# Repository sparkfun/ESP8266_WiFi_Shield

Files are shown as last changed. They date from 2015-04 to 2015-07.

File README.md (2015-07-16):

SparkFun ESP8266 WiFi Shield
========================================

SparkFun ESP8266 WiFi Shield

[*SparkFun ESP8266 WiFi Shield (WRL-13287)*](https://www.sparkfun.com/products/13287)

The [SparkFun ESP8266 WiFi Shield](https://www.sparkfun.com/products/13287) is essentially an Arduino shield for the ESP8266 WiFi SoC. The ESP8266 ships with a slightly customized version of the Espressif AT command set.

The ESP8266 is controlled by serial AT commands. The shield is equipped with a switch to swap between a software serial port or hardware serial port interface.

Repository Contents
-------------------

* **/Firmware** - Firmware flashed on the ESP8266 WiFi Shield (requires ESP8266 SDK 1.2.0)
* **/Hardware** - Eagle design files (.brd, .sch)
* **/Production** - Production panel files (.brd)

Documentation
--------------
* **[Hookup Guide](https://learn.sparkfun.com/tutorials/esp8266-wifi-shield-hookup-guide)** - Exhaustive hookup guide for the ESP8266 WiFi Shield.

Product Versions
----------------
* [DEV-13287](https://www.sparkfun.com/products/13287)- V1.0 release of the WiFi Shield.

License Information
-------------------
This product is _**open source**_! 

The **hardware** is released under [Creative Commons ShareAlike 4.0 International](https://creativecommons.org/licenses/by-sa/4.0/).

The **code** is beerware; if you see me (or any other SparkFun employee) at the local, and you've found our code helpful, please buy us a round!

Please use, reuse, and modify these files as you see fit. Please maintain attribution to SparkFun Electronics and release anyWiFi Shield derivative under the same license.

Distributed as-is; no warranty is given.

- Your friends at SparkFun.

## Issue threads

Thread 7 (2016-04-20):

Shield not working?

r3m4k3, 2016-04-20:
Hi there,

I have wired Arduino Mega 2560 with your shield.
I have uploaded demo code and it returns me false in line eso8266.begin(), what does it mean?
Does it mean, that the hardware is corrupt?
Then, how can I get information, what is precisely broken?
Can I check for example voltage or something for pins and then know or hardware is down, or maybe I had bad soldered the goldpins, or there is a short circuit.

Thanks, best regards

bboyho, 2019-02-11:
Hi,

I was checking something in the GitHub repository and noticed this issue filed.

###Software Serial Pins

The ESP8266 Shield was designed to stack on the Arduino Uno footprint with the ATmega328P microcontroller. Not all pins on the Arduino Mega 2560 support change interrupts for Rx so software serial will not work on pin 8. Check out this note from Arduino.cc on the Software Serial Library =>  [https://www.arduino.cc/en/Reference/softwareSerial](https://www.arduino.cc/en/Reference/softwareSerial) ]. You can probably get it working on the Arduino Mega 2560 by [redefining the library on pin 8](https://github.com/sparkfun/SparkFun_ESP8266_AT_Arduino_Library/blob/master/src/SparkFunESP8266WiFi.h#L34) to:

    #define ESP8266_SW_TX	10

You will also need to reroute the pin so that the ESP8266's Tx pin connects pin 10.

###Solder Joints

Just like any basic troubleshooting, you should also [check your solder joints](https://learn.sparkfun.com/tutorials/sparkfun-troubleshooting-tips#bad-solder-joints). However, I do not believe this is the issue.

Closed 2019-02-11.

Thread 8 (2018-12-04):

Arduino reset (and additional firmware features)

jaketesler, 2018-12-04:
Hello!
@jimblom SparkFun told me opening an issue here was the best avenue to ask my question to you directly.

I have a question regarding the most-recent published build of the ESP8266 shield firmware.
https://github.com/sparkfun/ESP8266_WiFi_Shield/blob/749e0c4b562e96147a4b3361443263421a739eb5/Firmware/include/user_config.h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 https://github.com/sparkfun/ESP8266_WiFi_Shield/blob/749e0c4b562e96147a4b3361443263421a739eb5/Firmware/user/at_ArduinoShield.c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

These two sections of the code seem to indicate that it's possible to reset an Arduino using no hardware modifications (except modifying SJ4), and furthermore the schematic (https://cdn.sparkfun.com/assets/learn_tutorials/4/0/3/SparkFun-ESP8266-WiFi-Shield.pdf) seems to indicate that, with the proper firmware build, this should be possible.

The current published build on this repo doesn't seem to include source code for these features, and the `AT+DUINORST` command doesn't currently work on my own shield.

My question is, is there another (newer) version of the firmware and a way I could acquire a build of it (or the source), or, if a newer version doesn't exist, would it be possible to upload the remainder of the codebase (for compilation) so I can work on coding and developing the features into the SF source code here?

Thanks Jim!
-Jake Tesler

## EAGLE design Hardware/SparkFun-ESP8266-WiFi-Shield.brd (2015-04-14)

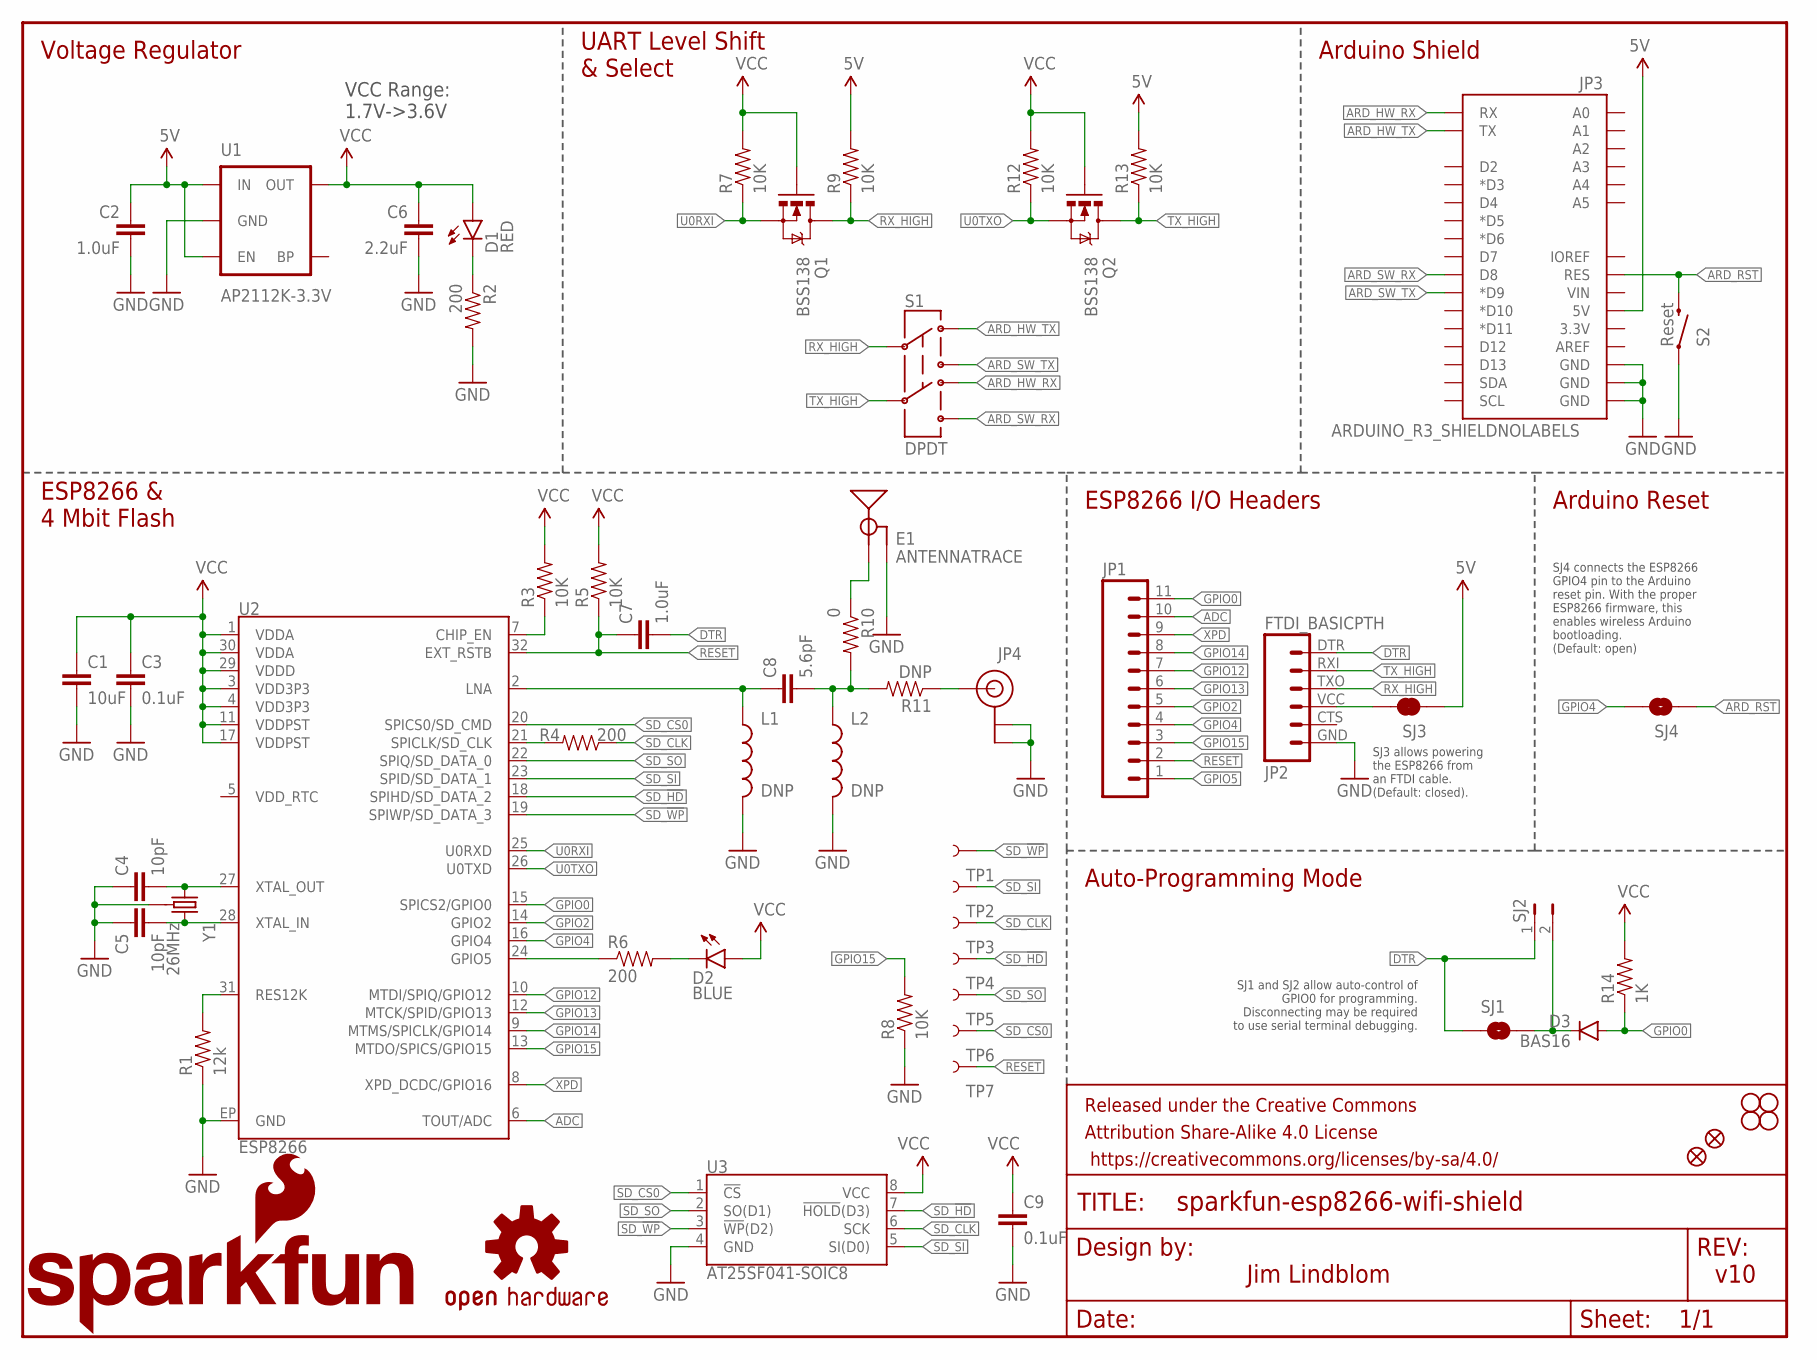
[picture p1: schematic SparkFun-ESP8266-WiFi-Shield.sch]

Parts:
C1: 10uF; 0603-CAP
C2: 1.0uF; 0805
C3, C9: 0.1uF; 0603-CAP
C4, C5: 10pF; 0603-CAP
C6: 2.2uF; 0603-CAP
C7: 1.0uF; 0603-CAP
C8: 5.6pF; 0603-CAP
D1: RED; LED-0603
D2: BLUE; LED-0603
D3: BAS16; SOD-323
E1: ANTENNATRACE; TRACE_ANTENNA_2.4GHZ_25.7MM
FID1, FID2: FIDUCIAL1X2; FIDUCIAL-1X2
FRAME1: FRAME-LETTER; CREATIVE_COMMONS
JP1: M11PTH; 1X11
JP2: FTDI_BASICPTH; FTDI_BASIC
JP3: ARDUINO_R3_SHIELDNOLABELS; UNO_R3_SHIELD_NOLABELS
JP4: U.FL
L1, L2: DNP; 0603
LOGO1: SFE_LOGO_NAME_FLAME.2_INCH; SFE_LOGO_NAME_FLAME_.2
LOGO2: OSHW-LOGOM; OSHW-LOGO-M
Q1, Q2: BSS138; SOT23-3
R1: 12k; 0603-RES
R2, R4, R6: 200; 0603-RES
R3, R5, R7, R8, R9, R12, R13: 10K; 0603-RES
R10: 0; 0603
R11: DNP; 0603-RES
R14: 1K; 0603-RES
S1: DPDT; AYZ0202
S2: Reset; TACTILE-SWITCH-SMD
SJ1: JUMPER-PAD-2-NO; PAD-JUMPER-2-NO_NO_SILK
SJ2: JUMPER-PTH-2-NO; PTH-JUMPER-2-NO_NO_SILK
SJ3: JUMPER-PAD-2-NC_BY_TRACE; PAD-JUMPER-2-NC_BY_TRACE_YES_SILK
SJ4: JUMPER-PAD-2-NOYES_SILK; PAD-JUMPER-2-NO_YES_SILK
STANDOFF1, STANDOFF2, STANDOFF3, STANDOFF4: STAND-OFF
TP1, TP2, TP3, TP4, TP5, TP6, TP7: TEST-POINT3X5; PAD.03X.05
U1: AP2112K-3.3V; SOT23-5
U2: ESP8266; QFN32
U3: AT25SF041-SOIC8; SO08
Y1: 26MHz; CRYSTAL-SMD-3.2X2.5

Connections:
5V: C2.1, JP3.5V, R9.2, R13.2, SJ3.1, U1.1 (IN), U1.3 (EN)
ADC: JP1.10, U2.6 (TOUT/ADC)
ANT: JP4.P$3 (SIGNAL), R11.1
ARD_HW_RX: JP3.RX, S1.4
ARD_HW_TX: JP3.TX, S1.1
ARD_RST: JP3.RES, S2.3 (2), SJ4.1
ARD_SW_RX: JP3.D8, S1.6
ARD_SW_TX: JP3.D9 (*D9), S1.3
CHIP_EN: R3.1, U2.7 (CHIP_EN)
DTR: C7.2, JP2.DTR (1), SJ1.1, SJ2.1
GND: C1.2, C2.2, C3.2, C4.1, C5.1, C6.2, C9.2, E1.GND, E1.GND2 (GND), JP2.GND (6), JP3.GND@0 (GND), JP3.GND@1 (GND), JP3.GND@2 (GND), JP4.P$1 (GND), JP4.P$2 (GND), L1.2, L2.2, R1.1, R2.2, R8.1, S2.1, U1.2 (GND), U2.EP (GND), U3.4 (GND), Y1.2 (GND), Y1.4 (GND)
GPIO0: D3.A, JP1.11, R14.1, U2.15 (SPICS2/GPIO0)
GPIO2: JP1.5, U2.14 (GPIO2)
GPIO4: JP1.4, SJ4.2, U2.16 (GPIO4)
GPIO5: JP1.1, R6.1, U2.24 (GPIO5)
GPIO12: JP1.7, U2.10 (MTDI/SPIQ/GPIO12)
GPIO13: JP1.6, U2.12 (MTCK/SPID/GPIO13)
GPIO14: JP1.8, U2.9 (MTMS/SPICLK/GPIO14)
GPIO15: JP1.3, R8.2, U2.13 (MTDO/SPICS/GPIO15)
LNA: C8.1, L1.1, U2.2 (LNA)
unnamed: R1.2, U2.31 (RES12K)
unnamed: C5.2, U2.28 (XTAL_IN), Y1.3 (2)
unnamed: C4.2, U2.27 (XTAL_OUT), Y1.1
unnamed: D1.C, R2.1
unnamed: C8.2, L2.1, R10.2, R11.2
unnamed: R4.2, U2.21 (SPICLK/SD_CLK)
unnamed: JP2.VCC (4), SJ3.2
unnamed: D2.C, R6.2
RESET: C7.1, JP1.2, R5.1, TP7.P$1, U2.32 (EXT_RSTB)
RX_HIGH: JP2.TXO (3), Q1.3 (D), R9.1, S1.2
SD_!HD!: TP4.P$1, U2.18 (SPIHD/SD_DATA_2), U3.7 (!HOLD!(D3))
SD_!WP!: TP1.P$1, U2.19 (SPIWP/SD_DATA_3), U3.3 (!WP!(D2))
SD_CLK: R4.1, TP3.P$1, U3.6 (SCK)
SD_CS0: TP6.P$1, U2.20 (SPICS0/SD_CMD), U3.1 (!CS!)
SD_SI: TP2.P$1, U2.23 (SPID/SD_DATA_1), U3.5 (SI(D0))
SD_SO: TP5.P$1, U2.22 (SPIQ/SD_DATA_0), U3.2 (SO(D1))
SJ2: D3.C, SJ1.2, SJ2.2
TRACE_ANT: E1.ANT (SIGNAL), R10.1
TX_HIGH: JP2.RXI (2), Q2.3 (D), R13.1, S1.5
U0RXI: Q1.2 (S), R7.1, U2.25 (U0RXD)
U0TXO: Q2.2 (S), R12.1, U2.26 (U0TXD)
VCC: C1.1, C3.1, C6.1, C9.1, D1.A, D2.A, Q1.1 (G), Q2.1 (G), R3.2, R5.2, R7.2, R12.2, R14.2, U1.5 (OUT), U2.1 (VDDA), U2.3 (VDD3P3), U2.4 (VDD3P3), U2.11 (VDDPST), U2.17 (VDDPST), U2.29 (VDDD), U2.30 (VDDA), U3.8 (VCC)
XPD: JP1.9, U2.8 (XPD_DCDC/GPIO16)

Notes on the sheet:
VCC Range: 1.7V->3.6V
SJ1 and SJ2 allow auto-control of GPIO0 for programming. Disconnecting may be required to use serial terminal debugging.
Auto-Programming Mode
ESP8266 I/O Headers
Arduino Shield
UART Level Shift & Select
Voltage Regulator
ESP8266 & 4 Mbit Flash
v10
Jim Lindblom
Arduino Reset
SJ4 connects the ESP8266 GPIO4 pin to the Arduino reset pin. With the proper ESP8266 firmware, this enables wireless Arduino bootloading. (Default: open)
SJ3 allows powering the ESP8266 from an FTDI cable. (Default: closed).

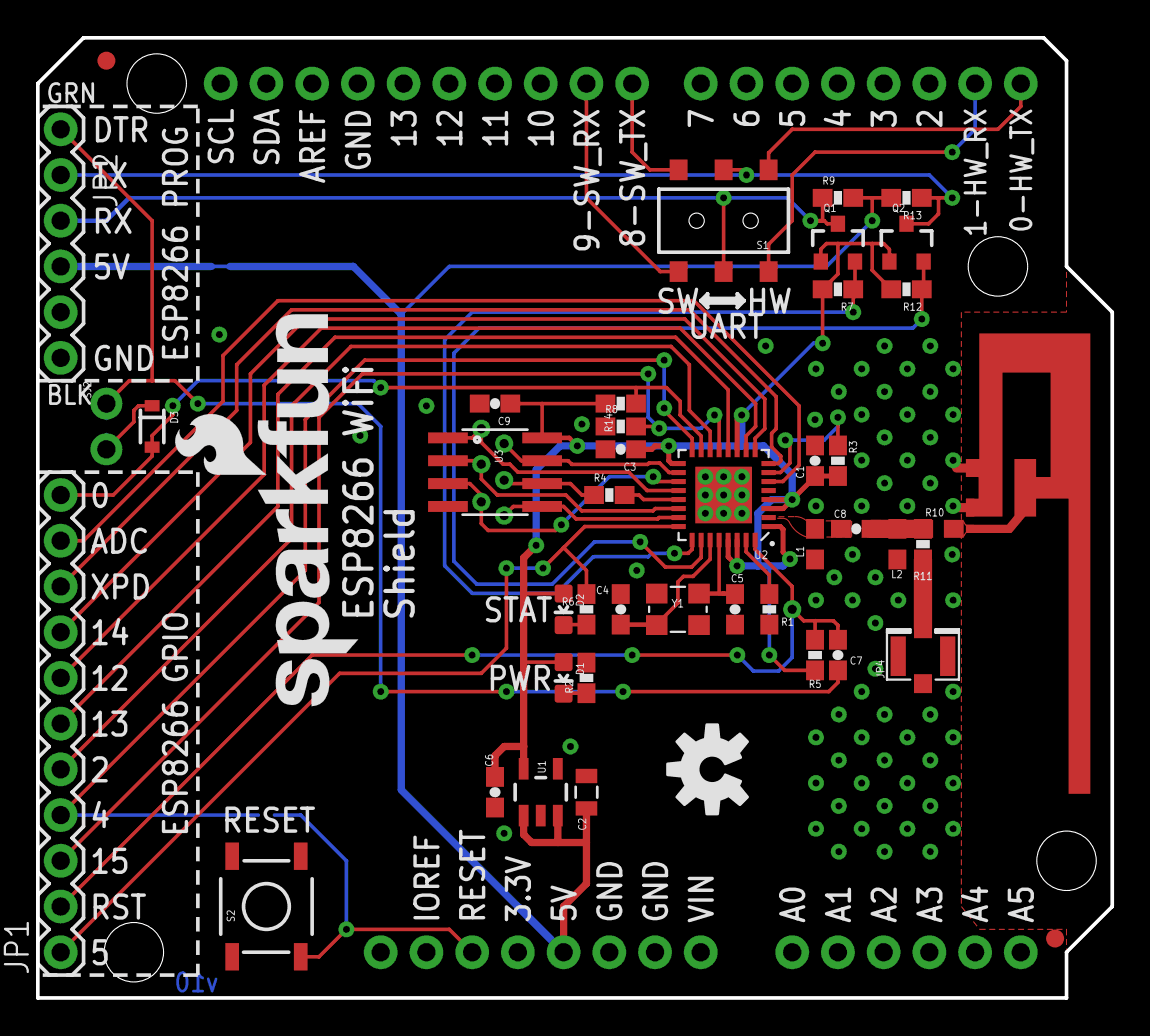
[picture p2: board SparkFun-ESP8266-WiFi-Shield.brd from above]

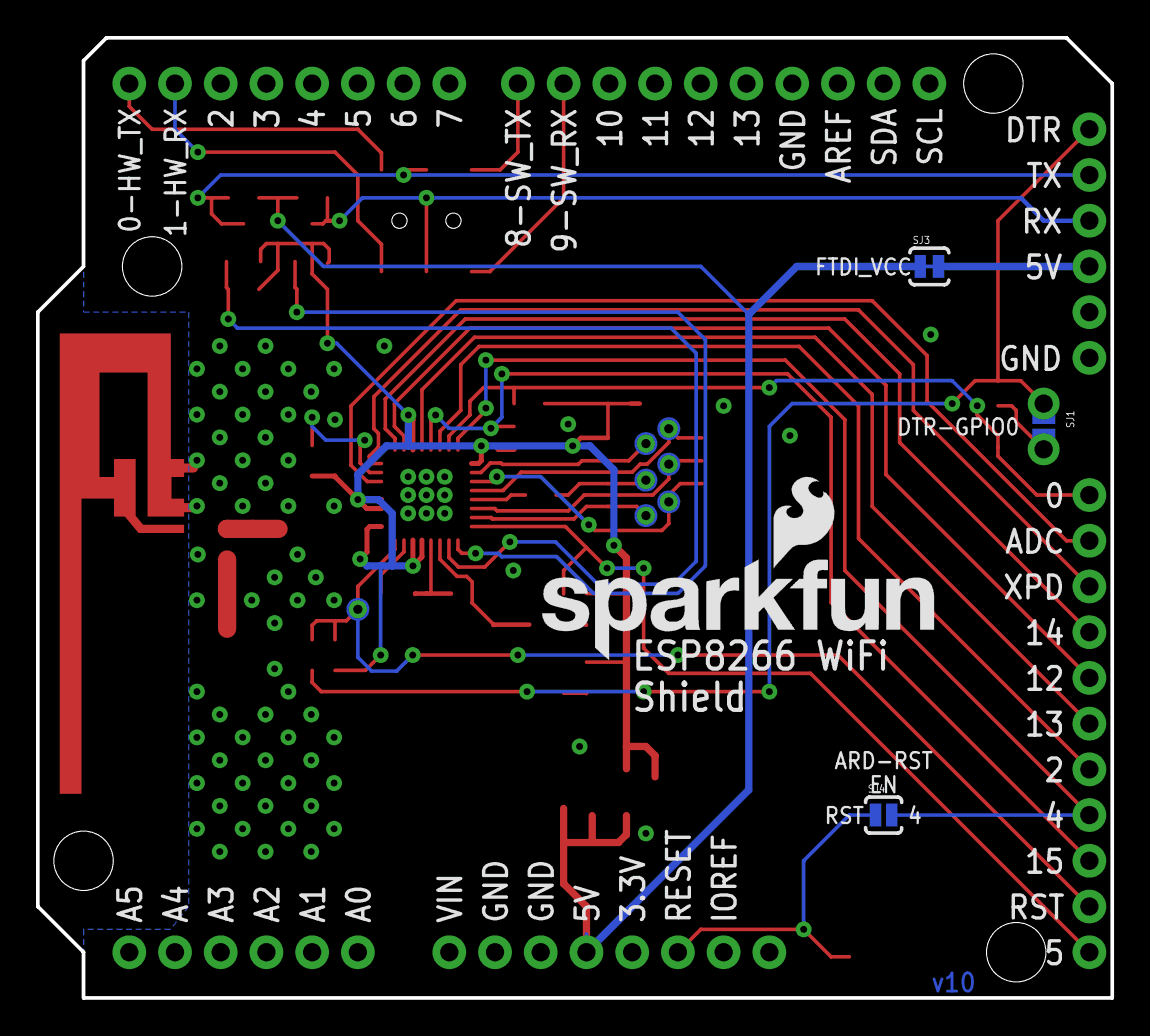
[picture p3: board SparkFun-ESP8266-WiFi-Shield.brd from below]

Board: 2 copper layers, 59.7 x 53.3 mm, 62 parts (11 on the bottom side), 43 nets.

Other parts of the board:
LOGO3: SFE_LOGO_NAME_FLAME.2_INCH; SFE_LOGO_NAME_FLAME_.2

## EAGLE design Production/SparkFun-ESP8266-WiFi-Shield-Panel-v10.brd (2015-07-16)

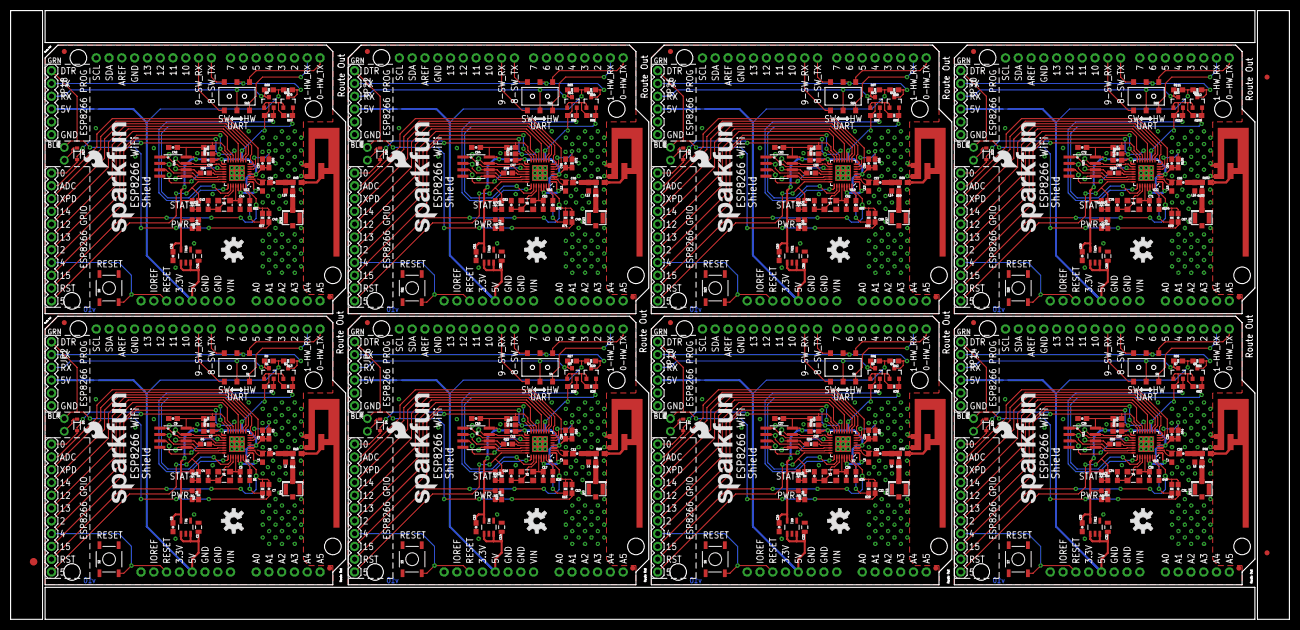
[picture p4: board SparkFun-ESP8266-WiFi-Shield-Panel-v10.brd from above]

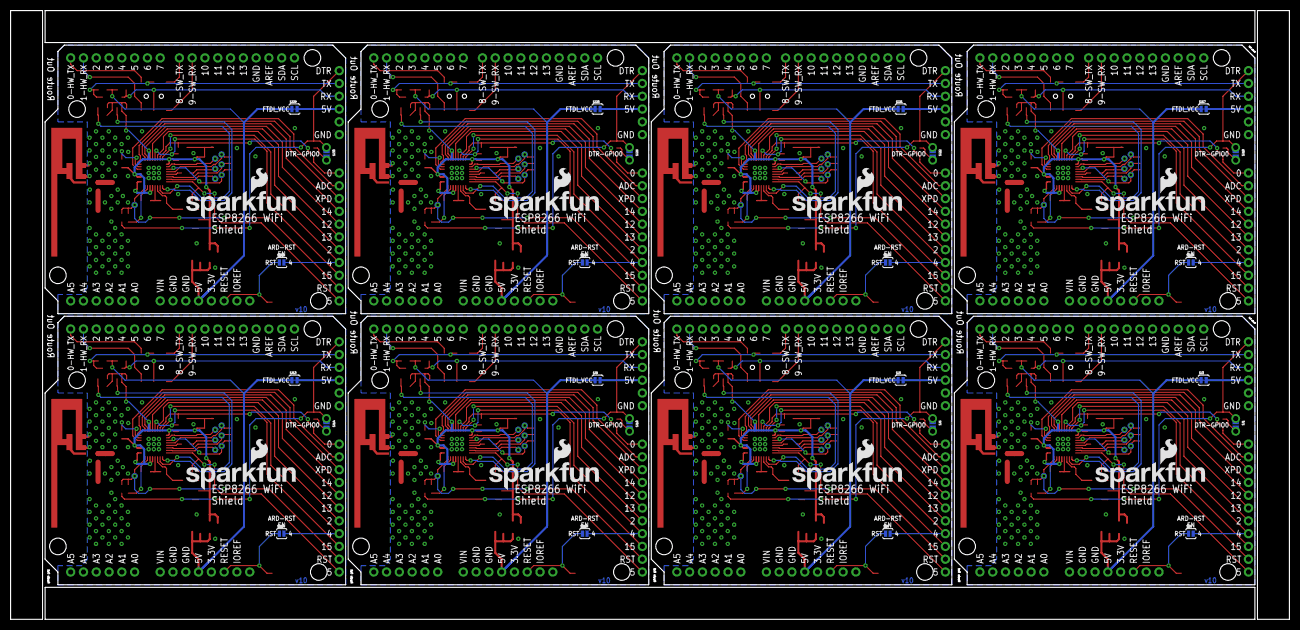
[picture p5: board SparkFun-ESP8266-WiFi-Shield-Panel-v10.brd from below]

Board: 2 copper layers, 254.0 x 120.9 mm, 491 parts (88 on the bottom side), 344 nets.

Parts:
C1, C10, C19, C28, C37, C46, C55, C64: 10uF; 0603-CAP
C2, C14, C23, C32, C41, C50, C59, C68: 1.0uF; 0805
C3, C9, C11, C18, C20, C27, C29, C36, C38, C45, C47, C54, C56, C63, C65, C72: 0.1uF; 0603-CAP
C4, C5, C16, C17, C25, C26, C34, C35, C43, C44, C52, C53, C61, C62, C70, C71: 10pF; 0603-CAP
C6, C15, C24, C33, C42, C51, C60, C69: 2.2uF; 0603-CAP
C7, C13, C22, C31, C40, C49, C58, C67: 1.0uF; 0603-CAP
C8, C12, C21, C30, C39, C48, C57, C66: 5.6pF; 0603-CAP
D1, D5, D8, D11, D14, D17, D20, D23: RED; LED-0603
D2, D6, D9, D12, D15, D18, D21, D24: BLUE; LED-0603
D3, D4, D7, D10, D13, D16, D19, D22: BAS16; SOD-323
E1, E2, E3, E4, E5, E6, E7, E8: ANTENNATRACE; TRACE_ANTENNA_2.4GHZ_25.7MM
E$1: FIDUCIAL-1.5X3
E$4, E$5: FIDUCIAL-1X2
FID1, FID2, FID3, FID4, FID5, FID6, FID7, FID8, FID9, FID10, FID11, FID12, FID13, FID14, FID15, FID16: FIDUCIAL1X2; FIDUCIAL-1X2
JP1, JP8, JP12, JP16, JP20, JP24, JP28, JP32: 1X11
JP2, JP6, JP10, JP14, JP18, JP22, JP26, JP30: FTDI_BASICPTH; FTDI_BASIC
JP3, JP5, JP9, JP13, JP17, JP21, JP25, JP29: ARDUINO_R3_SHIELDNOLABELS; UNO_R3_SHIELD_NOLABELS
JP4, JP7, JP11, JP15, JP19, JP23, JP27, JP31: U.FL
L1, L2, L3, L4, L5, L6, L7, L8, L9, L10, L11, L12, L13, L14, L15, L16: DNP; 0603
LOGO1, LOGO3, LOGO5, LOGO6, LOGO8, LOGO9, LOGO11, LOGO12, LOGO14, LOGO15, LOGO17, LOGO18, LOGO20, LOGO21, LOGO23, LOGO24: SFE_LOGO_NAME_FLAME.2_INCH; SFE_LOGO_NAME_FLAME_.2
LOGO2, LOGO4, LOGO7, LOGO10, LOGO13, LOGO16, LOGO19, LOGO22: OSHW-LOGOM; OSHW-LOGO-M
Q1, Q2, Q3, Q4, Q5, Q6, Q7, Q8, Q9, Q10, Q11, Q12, Q13, Q14, Q15, Q16: BSS138; SOT23-3
R1, R20, R34, R48, R62, R76, R90, R104: 12k; 0603-RES
R2, R4, R6, R21, R22, R23, R35, R36, R37, R49, R50, R51, R63, R64, R65, R77, R78, R79, R91, R92, R93, R105, R106, R107: 200; 0603-RES
R3, R5, R7, R8, R9, R12, R13, R15, R16, R24, R25, R26, R27, R28, R29, R30, R38, R39, R40, R41, R42, R43, R44, R52, R53, R54, R55, R56, R57, R58, R66, R67, R68, R69, R70, R71, R72, R80, R81, R82, R83, R84, R85, R86, R94, R95, R96, R97, R98, R99, R100, R108, R109, R110, R111, R112: 10K; 0603-RES
R10, R18, R32, R46, R60, R74, R88, R102: 0; 0603
R11, R19, R33, R47, R61, R75, R89, R103: DNP; 0603-RES
R14, R17, R31, R45, R59, R73, R87, R101: 1K; 0603-RES
S1, S4, S6, S8, S10, S12, S14, S16: DPDT; AYZ0202
S2, S3, S5, S7, S9, S11, S13, S15: Reset; TACTILE-SWITCH-SMD
SJ1, SJ6, SJ10, SJ14, SJ18, SJ22, SJ26, SJ30: PAD-JUMPER-2-NO_NO_SILK
SJ2, SJ7, SJ11, SJ15, SJ19, SJ23, SJ27, SJ31: PTH-JUMPER-2-NO_NO_SILK
SJ3, SJ5, SJ9, SJ13, SJ17, SJ21, SJ25, SJ29: PAD-JUMPER-2-NC_BY_TRACE_YES_SILK
SJ4, SJ8, SJ12, SJ16, SJ20, SJ24, SJ28, SJ32: PAD-JUMPER-2-NO_YES_SILK
STANDOFF1, STANDOFF2, STANDOFF3, STANDOFF4, STANDOFF5, STANDOFF6, STANDOFF7, STANDOFF8, STANDOFF9, STANDOFF10, STANDOFF11, STANDOFF12, STANDOFF13, STANDOFF14, STANDOFF15, STANDOFF16, STANDOFF17, STANDOFF18, STANDOFF19, STANDOFF20, STANDOFF21, STANDOFF22, STANDOFF23, STANDOFF24, STANDOFF25, STANDOFF26, STANDOFF27, STANDOFF28, STANDOFF29, STANDOFF30, STANDOFF31, STANDOFF32: STAND-OFF
TP1, TP2, TP3, TP4, TP5, TP6, TP7, TP8, TP9, TP10, TP11, TP12, TP13, TP14, TP15, TP16, TP17, TP18, TP19, TP20, TP21, TP22, TP23, TP24, TP25, TP26, TP27, TP28, TP29, TP30, TP31, TP32, TP33, TP34, TP35, TP36, TP37, TP38, TP39, TP40, TP41, TP42, TP43, TP44, TP45, TP46, TP47, TP48, TP49, TP50, TP51, TP52, TP53, TP54, TP55, TP56: PAD.03X.05
U1, U6, U9, U12, U15, U18, U21, U24: AP2112K-3.3V; SOT23-5
U2, U4, U7, U10, U13, U16, U19, U22: ESP8266; QFN32
U3, U5, U8, U11, U14, U17, U20, U23: AT25SF041-SOIC8; SO08
Y1, Y2, Y3, Y4, Y5, Y6, Y7, Y8: 26MHz; CRYSTAL-SMD-3.2X2.5

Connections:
5V: C2.1, JP3.5V, R9.2, R13.2, SJ3.1, U1.1, U1.3
5V1: C14.1, JP5.5V, R27.2, R28.2, SJ5.1, U6.1, U6.3
5V2: C23.1, JP9.5V, R41.2, R42.2, SJ9.1, U9.1, U9.3
5V3: C32.1, JP13.5V, R55.2, R56.2, SJ13.1, U12.1, U12.3
5V4: C41.1, JP17.5V, R69.2, R70.2, SJ17.1, U15.1, U15.3
5V5: C50.1, JP21.5V, R83.2, R84.2, SJ21.1, U18.1, U18.3
5V6: C59.1, JP25.5V, R97.2, R98.2, SJ25.1, U21.1, U21.3
5V7: C68.1, JP29.5V, R111.2, R112.2, SJ29.1, U24.1, U24.3
ADC: JP1.10, U2.6
ADC1: JP8.10, U4.6
ADC2: JP12.10, U7.6
ADC3: JP16.10, U10.6
ADC4: JP20.10, U13.6
ADC5: JP24.10, U16.6
ADC6: JP28.10, U19.6
ADC7: JP32.10, U22.6
ANT: JP4.P$3, R11.1
ANT1: JP7.P$3, R19.1
ANT2: JP11.P$3, R33.1
ANT3: JP15.P$3, R47.1
ANT4: JP19.P$3, R61.1
ANT5: JP23.P$3, R75.1
ANT6: JP27.P$3, R89.1
ANT7: JP31.P$3, R103.1
ARD_HW_RX: JP3.RX, S1.4
ARD_HW_RX1: JP5.RX, S4.4
ARD_HW_RX2: JP9.RX, S6.4
ARD_HW_RX3: JP13.RX, S8.4
ARD_HW_RX4: JP17.RX, S10.4
ARD_HW_RX5: JP21.RX, S12.4
ARD_HW_RX6: JP25.RX, S14.4
ARD_HW_RX7: JP29.RX, S16.4
ARD_HW_TX: JP3.TX, S1.1
ARD_HW_TX1: JP5.TX, S4.1
ARD_HW_TX2: JP9.TX, S6.1
ARD_HW_TX3: JP13.TX, S8.1
ARD_HW_TX4: JP17.TX, S10.1
ARD_HW_TX5: JP21.TX, S12.1
ARD_HW_TX6: JP25.TX, S14.1
ARD_HW_TX7: JP29.TX, S16.1
ARD_RST: JP3.RES, S2.3, SJ4.1
ARD_RST1: JP5.RES, S3.3, SJ8.1
ARD_RST2: JP9.RES, S5.3, SJ12.1
ARD_RST3: JP13.RES, S7.3, SJ16.1
ARD_RST4: JP17.RES, S9.3, SJ20.1
ARD_RST5: JP21.RES, S11.3, SJ24.1
ARD_RST6: JP25.RES, S13.3, SJ28.1
ARD_RST7: JP29.RES, S15.3, SJ32.1
ARD_SW_RX: JP3.D8, S1.6
ARD_SW_RX1: JP5.D8, S4.6
ARD_SW_RX2: JP9.D8, S6.6
ARD_SW_RX3: JP13.D8, S8.6
ARD_SW_RX4: JP17.D8, S10.6
ARD_SW_RX5: JP21.D8, S12.6
ARD_SW_RX6: JP25.D8, S14.6
ARD_SW_RX7: JP29.D8, S16.6
ARD_SW_TX: JP3.D9, S1.3
ARD_SW_TX1: JP5.D9, S4.3
ARD_SW_TX2: JP9.D9, S6.3
ARD_SW_TX3: JP13.D9, S8.3
ARD_SW_TX4: JP17.D9, S10.3
ARD_SW_TX5: JP21.D9, S12.3
ARD_SW_TX6: JP25.D9, S14.3
ARD_SW_TX7: JP29.D9, S16.3
CHIP_EN: R3.1, U2.7
CHIP_EN1: R16.1, U4.7
CHIP_EN2: R30.1, U7.7
CHIP_EN3: R44.1, U10.7
CHIP_EN4: R58.1, U13.7
CHIP_EN5: R72.1, U16.7
CHIP_EN6: R86.1, U19.7
CHIP_EN7: R100.1, U22.7
DTR: C7.2, JP2.DTR, SJ1.1, SJ2.1
DTR1: C13.2, JP6.DTR, SJ6.1, SJ7.1
DTR2: C22.2, JP10.DTR, SJ10.1, SJ11.1
DTR3: C31.2, JP14.DTR, SJ14.1, SJ15.1
DTR4: C40.2, JP18.DTR, SJ18.1, SJ19.1
DTR5: C49.2, JP22.DTR, SJ22.1, SJ23.1
DTR6: C58.2, JP26.DTR, SJ26.1, SJ27.1
DTR7: C67.2, JP30.DTR, SJ30.1, SJ31.1
GND: C1.2, C2.2, C3.2, C4.1, C5.1, C6.2, C9.2, E1.GND, E1.GND2, JP2.GND, JP3.GND@0, JP3.GND@1, JP3.GND@2, JP4.P$1, JP4.P$2, L1.2, L2.2, R1.1, R2.2, R8.1, S2.1, U1.2, U2.EP, U3.4, Y1.2, Y1.4
GND1: C10.2, C11.2, C14.2, C15.2, C16.1, C17.1, C18.2, E2.GND, E2.GND2, JP5.GND@0, JP5.GND@1, JP5.GND@2, JP6.GND, JP7.P$1, JP7.P$2, L3.2, L4.2, R20.1, R23.2, R24.1, S3.1, U4.EP, U5.4, U6.2, Y2.2, Y2.4
GND2: C19.2, C20.2, C23.2, C24.2, C25.1, C26.1, C27.2, E3.GND, E3.GND2, JP9.GND@0, JP9.GND@1, JP9.GND@2, JP10.GND, JP11.P$1, JP11.P$2, L5.2, L6.2, R34.1, R37.2, R38.1, S5.1, U7.EP, U8.4, U9.2, Y3.2, Y3.4
GND3: C28.2, C29.2, C32.2, C33.2, C34.1, C35.1, C36.2, E4.GND, E4.GND2, JP13.GND@0, JP13.GND@1, JP13.GND@2, JP14.GND, JP15.P$1, JP15.P$2, L7.2, L8.2, R48.1, R51.2, R52.1, S7.1, U10.EP, U11.4, U12.2, Y4.2, Y4.4
GND4: C37.2, C38.2, C41.2, C42.2, C43.1, C44.1, C45.2, E5.GND, E5.GND2, JP17.GND@0, JP17.GND@1, JP17.GND@2, JP18.GND, JP19.P$1, JP19.P$2, L9.2, L10.2, R62.1, R65.2, R66.1, S9.1, U13.EP, U14.4, U15.2, Y5.2, Y5.4
GND5: C46.2, C47.2, C50.2, C51.2, C52.1, C53.1, C54.2, E6.GND, E6.GND2, JP21.GND@0, JP21.GND@1, JP21.GND@2, JP22.GND, JP23.P$1, JP23.P$2, L11.2, L12.2, R76.1, R79.2, R80.1, S11.1, U16.EP, U17.4, U18.2, Y6.2, Y6.4
GND6: C55.2, C56.2, C59.2, C60.2, C61.1, C62.1, C63.2, E7.GND, E7.GND2, JP25.GND@0, JP25.GND@1, JP25.GND@2, JP26.GND, JP27.P$1, JP27.P$2, L13.2, L14.2, R90.1, R93.2, R94.1, S13.1, U19.EP, U20.4, U21.2, Y7.2, Y7.4
GND7: C64.2, C65.2, C68.2, C69.2, C70.1, C71.1, C72.2, E8.GND, E8.GND2, JP29.GND@0, JP29.GND@1, JP29.GND@2, JP30.GND, JP31.P$1, JP31.P$2, L15.2, L16.2, R104.1, R107.2, R108.1, S15.1, U22.EP, U23.4, U24.2, Y8.2, Y8.4
GPIO0: D3.A, JP1.11, R14.1, U2.15
GPIO1: JP8.8, U4.9
GPIO2: JP1.5, U2.14
GPIO3: D4.A, JP8.11, R17.1, U4.15
GPIO4: JP1.4, SJ4.2, U2.16
GPIO5: JP1.1, R6.1, U2.24
GPIO6: JP8.1, R21.1, U4.24
GPIO7: JP8.4, SJ8.2, U4.16
GPIO8: JP8.3, R24.2, U4.13
GPIO9: JP8.6, U4.12
GPIO10: JP8.7, U4.10
GPIO11: JP8.5, U4.14
GPIO12: JP1.7, U2.10
GPIO13: JP1.6, U2.12
GPIO14: JP1.8, U2.9
GPIO15: JP1.3, R8.2, U2.13
GPIO16: JP12.8, U7.9
GPIO17: D7.A, JP12.11, R31.1, U7.15
GPIO18: JP12.1, R35.1, U7.24
GPIO19: JP12.4, SJ12.2, U7.16
GPIO20: JP12.3, R38.2, U7.13
GPIO21: JP12.6, U7.12
GPIO22: JP12.7, U7.10
GPIO23: JP12.5, U7.14
GPIO24: JP16.8, U10.9
GPIO25: D10.A, JP16.11, R45.1, U10.15
GPIO26: JP16.1, R49.1, U10.24
GPIO27: JP16.4, SJ16.2, U10.16
GPIO28: JP16.3, R52.2, U10.13
GPIO29: JP16.6, U10.12
GPIO30: JP16.7, U10.10
GPIO31: JP16.5, U10.14
GPIO32: JP20.8, U13.9
GPIO33: D13.A, JP20.11, R59.1, U13.15
GPIO34: JP20.1, R63.1, U13.24
GPIO35: JP20.4, SJ20.2, U13.16
GPIO36: JP20.3, R66.2, U13.13
GPIO37: JP20.6, U13.12
GPIO38: JP20.7, U13.10
GPIO39: JP20.5, U13.14
GPIO40: JP24.8, U16.9
GPIO41: D16.A, JP24.11, R73.1, U16.15
GPIO42: JP24.1, R77.1, U16.24
GPIO43: JP24.4, SJ24.2, U16.16
GPIO44: JP24.3, R80.2, U16.13
GPIO45: JP24.6, U16.12
GPIO46: JP24.7, U16.10
GPIO47: JP24.5, U16.14
GPIO48: JP28.8, U19.9
GPIO49: D19.A, JP28.11, R87.1, U19.15
GPIO50: JP28.1, R91.1, U19.24
GPIO51: JP28.4, SJ28.2, U19.16
GPIO52: JP28.3, R94.2, U19.13
GPIO53: JP28.6, U19.12
GPIO54: JP28.7, U19.10
GPIO55: JP28.5, U19.14
GPIO56: JP32.8, U22.9
GPIO57: D22.A, JP32.11, R101.1, U22.15
GPIO58: JP32.1, R105.1, U22.24
GPIO59: JP32.4, SJ32.2, U22.16
GPIO60: JP32.3, R108.2, U22.13
GPIO61: JP32.6, U22.12
GPIO62: JP32.7, U22.10
GPIO63: JP32.5, U22.14
LNA: C8.1, L1.1, U2.2
LNA1: C12.1, L3.1, U4.2
LNA2: C21.1, L5.1, U7.2
LNA3: C30.1, L7.1, U10.2
LNA4: C39.1, L9.1, U13.2
LNA5: C48.1, L11.1, U16.2
LNA6: C57.1, L13.1, U19.2
LNA7: C66.1, L15.1, U22.2
unnamed: R1.2, U2.31
unnamed: C5.2, U2.28, Y1.3
unnamed: C4.2, U2.27, Y1.1
unnamed: D1.C, R2.1
unnamed: C8.2, L2.1, R10.2, R11.2
unnamed: R4.2, U2.21
unnamed: JP2.VCC, SJ3.2
unnamed: R20.2, U4.31
unnamed: D2.C, R6.2
unnamed: C17.2, U4.28, Y2.3
unnamed: C16.2, U4.27, Y2.1
unnamed: C12.2, L4.1, R18.2, R19.2
unnamed: R22.2, U4.21
unnamed: D5.C, R23.1
unnamed: JP6.VCC, SJ5.2
unnamed: D6.C, R21.2
unnamed: R34.2, U7.31
unnamed: C26.2, U7.28, Y3.3
unnamed: C25.2, U7.27, Y3.1
unnamed: C21.2, L6.1, R32.2, R33.2
unnamed: R36.2, U7.21
unnamed: D8.C, R37.1
unnamed: JP10.VCC, SJ9.2
unnamed: D9.C, R35.2
unnamed: R48.2, U10.31
unnamed: C35.2, U10.28, Y4.3
unnamed: C34.2, U10.27, Y4.1
unnamed: C30.2, L8.1, R46.2, R47.2
unnamed: R50.2, U10.21
unnamed: D11.C, R51.1
unnamed: JP14.VCC, SJ13.2
unnamed: D12.C, R49.2
unnamed: R62.2, U13.31
unnamed: C44.2, U13.28, Y5.3
unnamed: C43.2, U13.27, Y5.1
unnamed: C39.2, L10.1, R60.2, R61.2
unnamed: R64.2, U13.21
unnamed: D14.C, R65.1
unnamed: JP18.VCC, SJ17.2
unnamed: D15.C, R63.2
unnamed: R76.2, U16.31
unnamed: C53.2, U16.28, Y6.3
unnamed: C52.2, U16.27, Y6.1
unnamed: C48.2, L12.1, R74.2, R75.2
unnamed: R78.2, U16.21
unnamed: D17.C, R79.1
unnamed: JP22.VCC, SJ21.2
unnamed: D18.C, R77.2
unnamed: R90.2, U19.31
unnamed: C62.2, U19.28, Y7.3
unnamed: C61.2, U19.27, Y7.1
unnamed: C57.2, L14.1, R88.2, R89.2
unnamed: R92.2, U19.21
unnamed: D20.C, R93.1
unnamed: JP26.VCC, SJ25.2
unnamed: D21.C, R91.2
unnamed: R104.2, U22.31
unnamed: C71.2, U22.28, Y8.3
unnamed: C70.2, U22.27, Y8.1
unnamed: C66.2, L16.1, R102.2, R103.2
unnamed: R106.2, U22.21
unnamed: D23.C, R107.1
unnamed: JP30.VCC, SJ29.2
unnamed: D24.C, R105.2
RESET: C7.1, JP1.2, R5.1, TP7.P$1, U2.32
RESET1: C13.1, JP8.2, R15.1, TP8.P$1, U4.32
RESET2: C22.1, JP12.2, R29.1, TP15.P$1, U7.32
RESET3: C31.1, JP16.2, R43.1, TP22.P$1, U10.32
RESET4: C40.1, JP20.2, R57.1, TP29.P$1, U13.32
RESET5: C49.1, JP24.2, R71.1, TP36.P$1, U16.32
RESET6: C58.1, JP28.2, R85.1, TP43.P$1, U19.32
RESET7: C67.1, JP32.2, R99.1, TP50.P$1, U22.32
RX_HIGH: JP2.TXO, Q1.3, R9.1, S1.2
RX_HIGH1: JP6.TXO, Q3.3, R27.1, S4.2
RX_HIGH2: JP10.TXO, Q5.3, R41.1, S6.2
RX_HIGH3: JP14.TXO, Q7.3, R55.1, S8.2
RX_HIGH4: JP18.TXO, Q9.3, R69.1, S10.2
RX_HIGH5: JP22.TXO, Q11.3, R83.1, S12.2
RX_HIGH6: JP26.TXO, Q13.3, R97.1, S14.2
RX_HIGH7: JP30.TXO, Q15.3, R111.1, S16.2
SD_!HD!: TP4.P$1, U2.18, U3.7
SD_!HD!1: TP14.P$1, U4.18, U5.7
SD_!HD!2: TP21.P$1, U7.18, U8.7
SD_!HD!3: TP28.P$1, U10.18, U11.7
SD_!HD!4: TP35.P$1, U13.18, U14.7
SD_!HD!5: TP42.P$1, U16.18, U17.7
SD_!HD!6: TP49.P$1, U19.18, U20.7
SD_!HD!7: TP56.P$1, U22.18, U23.7
SD_!WP!: TP1.P$1, U2.19, U3.3
SD_!WP!1: TP11.P$1, U4.19, U5.3
SD_!WP!2: TP18.P$1, U7.19, U8.3
SD_!WP!3: TP25.P$1, U10.19, U11.3
SD_!WP!4: TP32.P$1, U13.19, U14.3
SD_!WP!5: TP39.P$1, U16.19, U17.3
SD_!WP!6: TP46.P$1, U19.19, U20.3
SD_!WP!7: TP53.P$1, U22.19, U23.3
SD_CLK: R4.1, TP3.P$1, U3.6
SD_CLK1: R22.1, TP13.P$1, U5.6
SD_CLK2: R36.1, TP20.P$1, U8.6
SD_CLK3: R50.1, TP27.P$1, U11.6
SD_CLK4: R64.1, TP34.P$1, U14.6
SD_CLK5: R78.1, TP41.P$1, U17.6
SD_CLK6: R92.1, TP48.P$1, U20.6
SD_CLK7: R106.1, TP55.P$1, U23.6
SD_CS0: TP6.P$1, U2.20, U3.1
SD_CS1: TP9.P$1, U4.20, U5.1
SD_CS2: TP16.P$1, U7.20, U8.1
SD_CS3: TP23.P$1, U10.20, U11.1
SD_CS4: TP30.P$1, U13.20, U14.1
SD_CS5: TP37.P$1, U16.20, U17.1
SD_CS6: TP44.P$1, U19.20, U20.1
SD_CS7: TP51.P$1, U22.20, U23.1
SD_SI: TP2.P$1, U2.23, U3.5
SD_SI1: TP12.P$1, U4.23, U5.5
SD_SI2: TP19.P$1, U7.23, U8.5
SD_SI3: TP26.P$1, U10.23, U11.5
SD_SI4: TP33.P$1, U13.23, U14.5
SD_SI5: TP40.P$1, U16.23, U17.5
SD_SI6: TP47.P$1, U19.23, U20.5
SD_SI7: TP54.P$1, U22.23, U23.5
SD_SO: TP5.P$1, U2.22, U3.2
SD_SO1: TP10.P$1, U4.22, U5.2
SD_SO2: TP17.P$1, U7.22, U8.2
SD_SO3: TP24.P$1, U10.22, U11.2
SD_SO4: TP31.P$1, U13.22, U14.2
SD_SO5: TP38.P$1, U16.22, U17.2
SD_SO6: TP45.P$1, U19.22, U20.2
SD_SO7: TP52.P$1, U22.22, U23.2
SJ1: D4.C, SJ6.2, SJ7.2
SJ2: D3.C, SJ1.2, SJ2.2
SJ3: D7.C, SJ10.2, SJ11.2
SJ4: D10.C, SJ14.2, SJ15.2
SJ5: D13.C, SJ18.2, SJ19.2
SJ6: D16.C, SJ22.2, SJ23.2
SJ7: D19.C, SJ26.2, SJ27.2
SJ8: D22.C, SJ30.2, SJ31.2
TRACE_ANT: E1.ANT, R10.1
TRACE_ANT1: E2.ANT, R18.1
TRACE_ANT2: E3.ANT, R32.1
TRACE_ANT3: E4.ANT, R46.1
TRACE_ANT4: E5.ANT, R60.1
TRACE_ANT5: E6.ANT, R74.1
TRACE_ANT6: E7.ANT, R88.1
TRACE_ANT7: E8.ANT, R102.1
TX_HIGH: JP2.RXI, Q2.3, R13.1, S1.5
TX_HIGH1: JP6.RXI, Q4.3, R28.1, S4.5
TX_HIGH2: JP10.RXI, Q6.3, R42.1, S6.5
TX_HIGH3: JP14.RXI, Q8.3, R56.1, S8.5
TX_HIGH4: JP18.RXI, Q10.3, R70.1, S10.5
TX_HIGH5: JP22.RXI, Q12.3, R84.1, S12.5
TX_HIGH6: JP26.RXI, Q14.3, R98.1, S14.5
TX_HIGH7: JP30.RXI, Q16.3, R112.1, S16.5
U0RXI: Q1.2, R7.1, U2.25
U0RXI1: Q3.2, R26.1, U4.25
U0RXI2: Q5.2, R40.1, U7.25
U0RXI3: Q7.2, R54.1, U10.25
U0RXI4: Q9.2, R68.1, U13.25
U0RXI5: Q11.2, R82.1, U16.25
U0RXI6: Q13.2, R96.1, U19.25
U0RXI7: Q15.2, R110.1, U22.25
U0TXO: Q2.2, R12.1, U2.26
U0TXO1: Q4.2, R25.1, U4.26
U0TXO2: Q6.2, R39.1, U7.26
U0TXO3: Q8.2, R53.1, U10.26
U0TXO4: Q10.2, R67.1, U13.26
U0TXO5: Q12.2, R81.1, U16.26
U0TXO6: Q14.2, R95.1, U19.26
U0TXO7: Q16.2, R109.1, U22.26
VCC: C1.1, C3.1, C6.1, C9.1, D1.A, D2.A, Q1.1, Q2.1, R3.2, R5.2, R7.2, R12.2, R14.2, U1.5, U2.1, U2.3, U2.4, U2.11, U2.17, U2.29, U2.30, U3.8
VCC1: C10.1, C11.1, C15.1, C18.1, D5.A, D6.A, Q3.1, Q4.1, R15.2, R16.2, R17.2, R25.2, R26.2, U4.1, U4.3, U4.4, U4.11, U4.17, U4.29, U4.30, U5.8, U6.5
VCC2: C19.1, C20.1, C24.1, C27.1, D8.A, D9.A, Q5.1, Q6.1, R29.2, R30.2, R31.2, R39.2, R40.2, U7.1, U7.3, U7.4, U7.11, U7.17, U7.29, U7.30, U8.8, U9.5
VCC3: C28.1, C29.1, C33.1, C36.1, D11.A, D12.A, Q7.1, Q8.1, R43.2, R44.2, R45.2, R53.2, R54.2, U10.1, U10.3, U10.4, U10.11, U10.17, U10.29, U10.30, U11.8, U12.5
VCC4: C37.1, C38.1, C42.1, C45.1, D14.A, D15.A, Q9.1, Q10.1, R57.2, R58.2, R59.2, R67.2, R68.2, U13.1, U13.3, U13.4, U13.11, U13.17, U13.29, U13.30, U14.8, U15.5
VCC5: C46.1, C47.1, C51.1, C54.1, D17.A, D18.A, Q11.1, Q12.1, R71.2, R72.2, R73.2, R81.2, R82.2, U16.1, U16.3, U16.4, U16.11, U16.17, U16.29, U16.30, U17.8, U18.5
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

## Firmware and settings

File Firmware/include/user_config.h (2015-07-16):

#ifndef __USER_CONFIG_H__
#define __USER_CONFIG_H__

#include "eagle_soc.h"

#define AT_CUSTOM_UPGRADE

#define DEFAULT_BAUD_RATE 9600

#define WELCOME_MESSAGE "READY!"

#define STATUS_LED_PIN  5
#define STATUS_LED_FUNC FUNC_GPIO5
#define STATUS_LED_MUX  PERIPHS_IO_MUX_GPIO5_U

#define ARDUINO_RESET_PIN	4

#define HIGH 1
#define LOW  0

#define UART0 0

#define SET_DUINO_RST_CMD "+DUINORST"
#define SET_DUINO_RST_CMD_SIZE 9

#define SET_PINMODE_CMD "+PINMODE"
#define SET_PINMODE_CMD_SIZE 8

#define WRITE_PIN_CMD "+PINWRITE"
#define WRITE_PIN_CMD_SIZE 9

#define READ_PIN_CMD "+PINREAD"
#define READ_PIN_CMD_SIZE 8

#endif

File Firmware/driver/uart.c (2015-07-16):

/******************************************************************************
 * Copyright 2013-2014 Espressif Systems (Wuxi)
 *
 * FileName: uart.c
 *
 * Description: Two UART mode configration and interrupt handler.
 *              Check your hardware connection while use this mode.
 *
 * Modification history:
 *     2014/3/12, v1.0 create this file.
*******************************************************************************/
#include "ets_sys.h"
#include "osapi.h"
#include "driver/uart.h"
#include "user_config.h"

#define UART0   0
#define UART1   1

// UartDev is defined and initialized in rom code.
extern UartDevice UartDev;

LOCAL void uart0_rx_intr_handler(void *para);

/******************************************************************************
 * FunctionName : uart_config
 * Description  : Internal used function
 *                UART0 used for data TX/RX, RX buffer size is 0x100, interrupt enabled
 *                UART1 just used for debug output
 * Parameters   : uart_no, use UART0 or UART1 defined ahead
 * Returns      : NONE
*******************************************************************************/
LOCAL void ICACHE_FLASH_ATTR
uart_config(uint8 uart_no)
{
    if (uart_no == UART1) {
        PIN_FUNC_SELECT(PERIPHS_IO_MUX_GPIO2_U, FUNC_U1TXD_BK);
    } else {
        /* rcv_buff size if 0x100 */
        ETS_UART_INTR_ATTACH(uart0_rx_intr_handler,  &(UartDev.rcv_buff));
        PIN_PULLUP_DIS(PERIPHS_IO_MUX_U0TXD_U);
        PIN_FUNC_SELECT(PERIPHS_IO_MUX_U0TXD_U, FUNC_U0TXD);
    }

    uart_div_modify(uart_no, UART_CLK_FREQ / (UartDev.baut_rate));

    WRITE_PERI_REG(UART_CONF0(uart_no),    UartDev.exist_parity
                   | UartDev.parity
                   | (UartDev.stop_bits << UART_STOP_BIT_NUM_S)
                   | (UartDev.data_bits << UART_BIT_NUM_S));


    //clear rx and tx fifo,not ready
    SET_PERI_REG_MASK(UART_CONF0(uart_no), UART_RXFIFO_RST | UART_TXFIFO_RST);
    CLEAR_PERI_REG_MASK(UART_CONF0(uart_no), UART_RXFIFO_RST | UART_TXFIFO_RST);

    //set rx fifo trigger
    WRITE_PERI_REG(UART_CONF1(uart_no), (UartDev.rcv_buff.TrigLvl & UART_RXFIFO_FULL_THRHD) << UART_RXFIFO_FULL_THRHD_S);

    //clear all interrupt
    WRITE_PERI_REG(UART_INT_CLR(uart_no), 0xffff);
    //enable rx_interrupt
    SET_PERI_REG_MASK(UART_INT_ENA(uart_no), UART_RXFIFO_FULL_INT_ENA);
}

/******************************************************************************
 * FunctionName : uart1_tx_one_char
 * Description  : Internal used function
 *                Use uart1 interface to transfer one char
 * Parameters   : uint8 TxChar - character to tx
 * Returns      : OK
*******************************************************************************/
LOCAL STATUS ICACHE_FLASH_ATTR
uart1_tx_one_char(uint8 TxChar)
{
    while (true)
	{
		uint32 fifo_cnt = READ_PERI_REG(UART_STATUS(UART1)) & (UART_TXFIFO_CNT<<UART_TXFIFO_CNT_S);
		if ((fifo_cnt >> UART_TXFIFO_CNT_S & UART_TXFIFO_CNT) < 126) {
			break;
		}
	}

	WRITE_PERI_REG(UART_FIFO(UART1) , TxChar);
	return OK;
}

/******************************************************************************
 * FunctionName : uart1_write_char
 * Description  : Internal used function
 *                Do some special deal while tx char is '\r' or '\n'
 * Parameters   : char c - character to tx
 * Returns      : NONE
*******************************************************************************/
LOCAL void ICACHE_FLASH_ATTR
uart1_write_char(char c)
{
    if (c == '\n') {
        uart1_tx_one_char('\r');
        uart1_tx_one_char('\n');
    } else if (c == '\r') {
    } else {
        uart1_tx_one_char(c);
    }
}

/******************************************************************************
 * FunctionName : uart0_rx_intr_handler
 * Description  : Internal used function
 *                UART0 interrupt handler, add self handle code inside
 * Parameters   : void *para - point to ETS_UART_INTR_ATTACH's arg
 * Returns      : NONE
*******************************************************************************/
LOCAL void
uart0_rx_intr_handler(void *para)
{
    /* uart0 and uart1 intr combine togther, when interrupt occur, see reg 0x3ff20020, bit2, bit0 represents
     * uart1 and uart0 respectively
     */
    RcvMsgBuff *pRxBuff = (RcvMsgBuff *)para;
    uint8 RcvChar;

    if (UART_RXFIFO_FULL_INT_ST != (READ_PERI_REG(UART_INT_ST(UART0)) & UART_RXFIFO_FULL_INT_ST)) {
        return;
    }

    WRITE_PERI_REG(UART_INT_CLR(UART0), UART_RXFIFO_FULL_INT_CLR);

    while (READ_PERI_REG(UART_STATUS(UART0)) & (UART_RXFIFO_CNT << UART_RXFIFO_CNT_S)) {
        RcvChar = READ_PERI_REG(UART_FIFO(UART0)) & 0xFF;

        /* you can add your handle code below.*/

        *(pRxBuff->pWritePos) = RcvChar;
		
        // insert here for get one command line from uart
        if (RcvChar == '\r') {
            pRxBuff->BuffState = WRITE_OVER;
        }

        pRxBuff->pWritePos++;

        if (pRxBuff->pWritePos == (pRxBuff->pRcvMsgBuff + RX_BUFF_SIZE)) {
            // overflow ...we may need more error handle here.
            pRxBuff->pWritePos = pRxBuff->pRcvMsgBuff ;
        }
    }
}


/******************************************************************************
 * FunctionName : uart0_tx_buffer
 * Description  : use uart0 to transfer buffer
 * Parameters   : uint8 *buf - point to send buffer
 *                uint16 len - buffer len
 * Returns      :
*******************************************************************************/
void ICACHE_FLASH_ATTR
uart0_tx_buffer(uint8 *buf, uint16 len)
{
    uint16 i;

    for (i = 0; i < len; i++) {
        uart_tx_one_char(buf[i]);
    }
}

/******************************************************************************
 * FunctionName : uart_init
 * Description  : user interface for init uart
 * Parameters   : UartBautRate uart0_br - uart0 bautrate
 *                UartBautRate uart1_br - uart1 bautrate
 * Returns      : NONE
*******************************************************************************/
void ICACHE_FLASH_ATTR
uart_init(UartBautRate uart0_br, UartBautRate uart1_br)
{
    // rom use 74880 baut_rate, here reinitialize
    UartDev.baut_rate = uart0_br;
    uart_config(UART0);
    UartDev.baut_rate = uart1_br;
    uart_config(UART1);
    ETS_UART_INTR_ENABLE();

    // install uart1 putc callback
    os_install_putc1((void *)uart1_write_char);
}

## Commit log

2015-02-09 Initial commit of hardware.
    [SparkFun-ESP8266-WiFi-Shield.brd, SparkFun-ESP8266-WiFi-Shield.sch]
2015-02-10 Fixing U.FL name and value, minor re-routing.
    [SparkFun-ESP8266-WiFi-Shield.brd, SparkFun-ESP8266-WiFi-Shield.sch]
2015-04-10 Changing STAT LED to active low.
    [SparkFun-ESP8266-WiFi-Shield.brd, SparkFun-ESP8266-WiFi-Shield.sch]
2015-04-10 Connecting GPIO4 to Arduino RST.
    Upping version to v10.
    Should allow for remote bootloading.
    Jumper in-line to disconnect if necessary.
    Defaulting DTR jumpers to open.
    [SparkFun-ESP8266-WiFi-Shield.brd, SparkFun-ESP8266-WiFi-Shield.sch]
2015-04-13 Breaking out ESP8266 reset pin.
    Moved the FTDI header to avoid interfering with screw head.
    Moved position of GPIO5 break out.
    Renamed GPIO16 to XPD.
    [SparkFun-ESP8266-WiFi-Shield.brd, SparkFun-ESP8266-WiFi-Shield.sch]
2015-04-13 Cleaning up schematic.
    [SparkFun-ESP8266-WiFi-Shield.brd, SparkFun-ESP8266-WiFi-Shield.sch]
2015-04-14 Minor mods after running checklist.
    [SparkFun-ESP8266-WiFi-Shield.brd, SparkFun-ESP8266-WiFi-Shield.sch]
2015-04-14 Small re-routes to increase ground plane coverage.
    [SparkFun-ESP8266-WiFi-Shield.brd]
2015-04-21 created panel v10
    [SparkFun-ESP8266-WiFi-Shield-Panel-v10.brd]
2015-07-16 Uppercasing 'h' in "Hardware"
    [SparkFun-ESP8266-WiFi-Shield.brd, SparkFun-ESP8266-WiFi-Shield.sch]
2015-07-16 Renaming "Production_Files" folder to "Production"
    [SparkFun-ESP8266-WiFi-Shield-Panel-v10.brd]

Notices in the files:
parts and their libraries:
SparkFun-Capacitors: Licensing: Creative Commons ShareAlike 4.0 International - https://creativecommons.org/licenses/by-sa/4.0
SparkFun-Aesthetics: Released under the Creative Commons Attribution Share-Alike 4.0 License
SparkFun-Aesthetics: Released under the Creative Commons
